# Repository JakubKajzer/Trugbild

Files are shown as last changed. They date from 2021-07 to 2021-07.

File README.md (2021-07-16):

# Trugbild
A FPGA working in serial with HDMI, for some real live video modifications. I'm making it to prove myself, that I can route highspeed PCB and to learn to code FPGA better.

## Features

- Xilinx Spartan 3 XC3S50A
- 2MB Flash memory
- 32MB DRAM memory
- Possibility to power device only from HDMI or from external input

## PCB screenshots
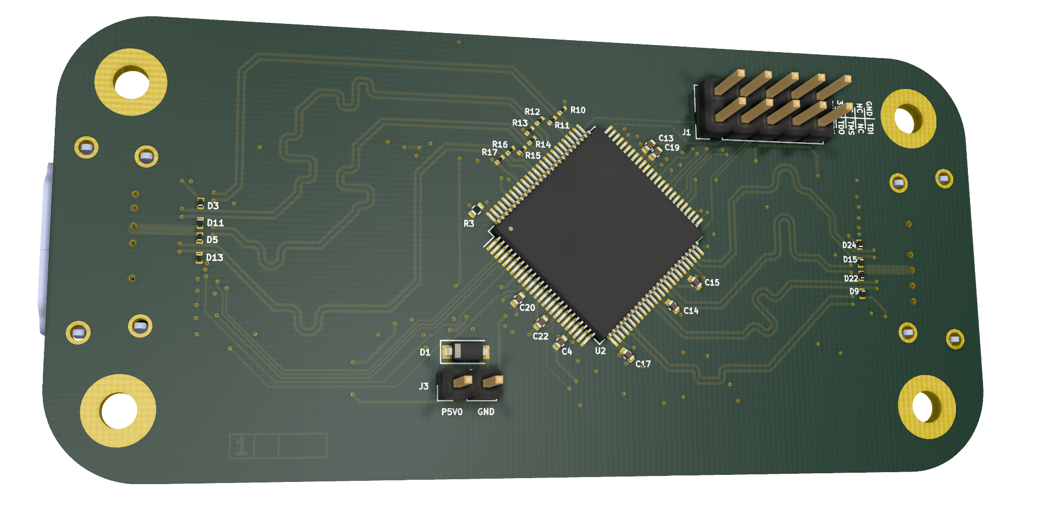
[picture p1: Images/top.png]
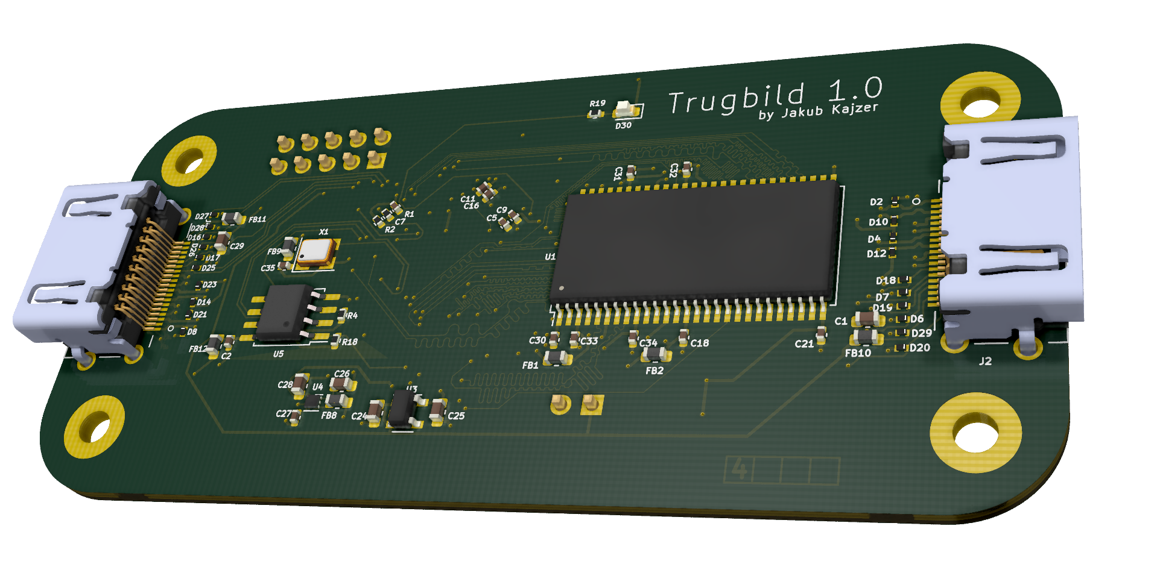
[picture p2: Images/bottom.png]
|||
|---|---|
## Why "Trugbild"
It is because Trugbild is a german word meaning _illusion_. So I think that is a good name for device which can modify what you see :)

## Develop steps
- [x] Make PCB

- [x] Order PCB fabrication
- [ ] Order elements
- [ ] Solder everything
- [ ] First run
- [ ] Try to run device only with power from HDMI (max. 50mA@5V)
- [ ] Make and test if device can transmit HDMI at Full HD
- [ ] Make some video modification while transmitting
- [ ] Try to add some kind of neuron network to face recognition
- [ ] Try to cover detected faces with some picture or someone face :)
## Comments
### Make PCB
This point took me many hours of designing because this is my first design with FPGA, so I had pretty much to learn. I'm still not sure if everything was routed least good, but I will find it out soon.
### Order PCB fabrication
For this, I used JLCPCB. They have 3.5mils clearance and track width, 0.2mm holes minimum, and four layers just for 8$. That's incredible!
But after uploading gerber files, it comes that they don't have 3.5mils clearance, but 0.09mm (3.543mils), so I must re-route some nets on PCB :( The 5 PCBs cost me total of $15.89 with delivery included.

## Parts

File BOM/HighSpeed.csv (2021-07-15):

Id | Designator | Package | Quantity | Designation | Supplier and ref
1 | REF**,REF**,REF**,REF** | MountingHole_3mm_Pad | 4 | MountingHole_3mm_Pad
2 | U1 | TSOP-II-54_22.2x10.16mm_P0.8mm | 1 | AS4C32M8SA-6TIN
3 | U2 | VQFP-100_14x14mm_P0.5mm | 1 | XC3S50A-4VQG100C
4 | J1 | PinHeader_2x05_P2.54mm_Vertical | 1 | Conn_02x05_Odd_Even
5 | U5 | SOP-8_5.28x5.23mm_P1.27mm | 1 | MX25L1636EM2I-08G
6 | R19 | R_0402_1005Metric | 1 | 1k
7 | D30 | LED_0603_1608Metric | 1 | LED
8 | R18,R4 | R_0402_1005Metric | 2 | 10k
9 | FB12,FB11,FB10,FB9,FB8,FB2,FB1 | L_0603_1608Metric | 7 | Ferrite_Bead_Small
10 | C2,C35,C34,C33,C32,C31,C30,C27,C22,C21,C20,C19,C18,C17,C16,C15,C14,C13,C11,C9,C7,C5,C4 | C_0402_1005Metric | 23 | 100nF
11 | R17,R16,R15,R14,R13,R12,R11,R10 | R_0201_0603Metric | 8 | 49R9
12 | X1 | Oscillator_SMD_SeikoEpson_SG8002CE-4Pin_3.2x2.5mm | 1 | EC5645ETTS-50.000M
13 | C1,C29,C28,C26,C25,C24 | C_0603_1608Metric | 6 | 100uF
14 | R3,R2,R1 | R_0402_1005Metric | 3 | DNP
15 | D28,D29,D27,D26,D25,D24,D23,D22,D21,D20,D19,D18,D17,D16,D15,D14,D13,D12,D11,D10,D9,D8,D7,D6,D5,D4,D3,D2 | DFN-2 | 28 | AOZ8831DI-05
16 | J4,J2 | AMPHENOL_10029449-001RLF | 2 | HDMI_A
17 | D1 | D_SOD-123 | 1 | BAT46
18 | U4 | DFN-6_1.3x1.2mm_P0.4mm | 1 | LDK130PU12R_DFN6
19 | U3 | SOT-23-5 | 1 | MIC5365-3.3YD5
20 | J3 | PinHeader_1x02_P2.54mm_Vertical | 1 | Conn_01x02

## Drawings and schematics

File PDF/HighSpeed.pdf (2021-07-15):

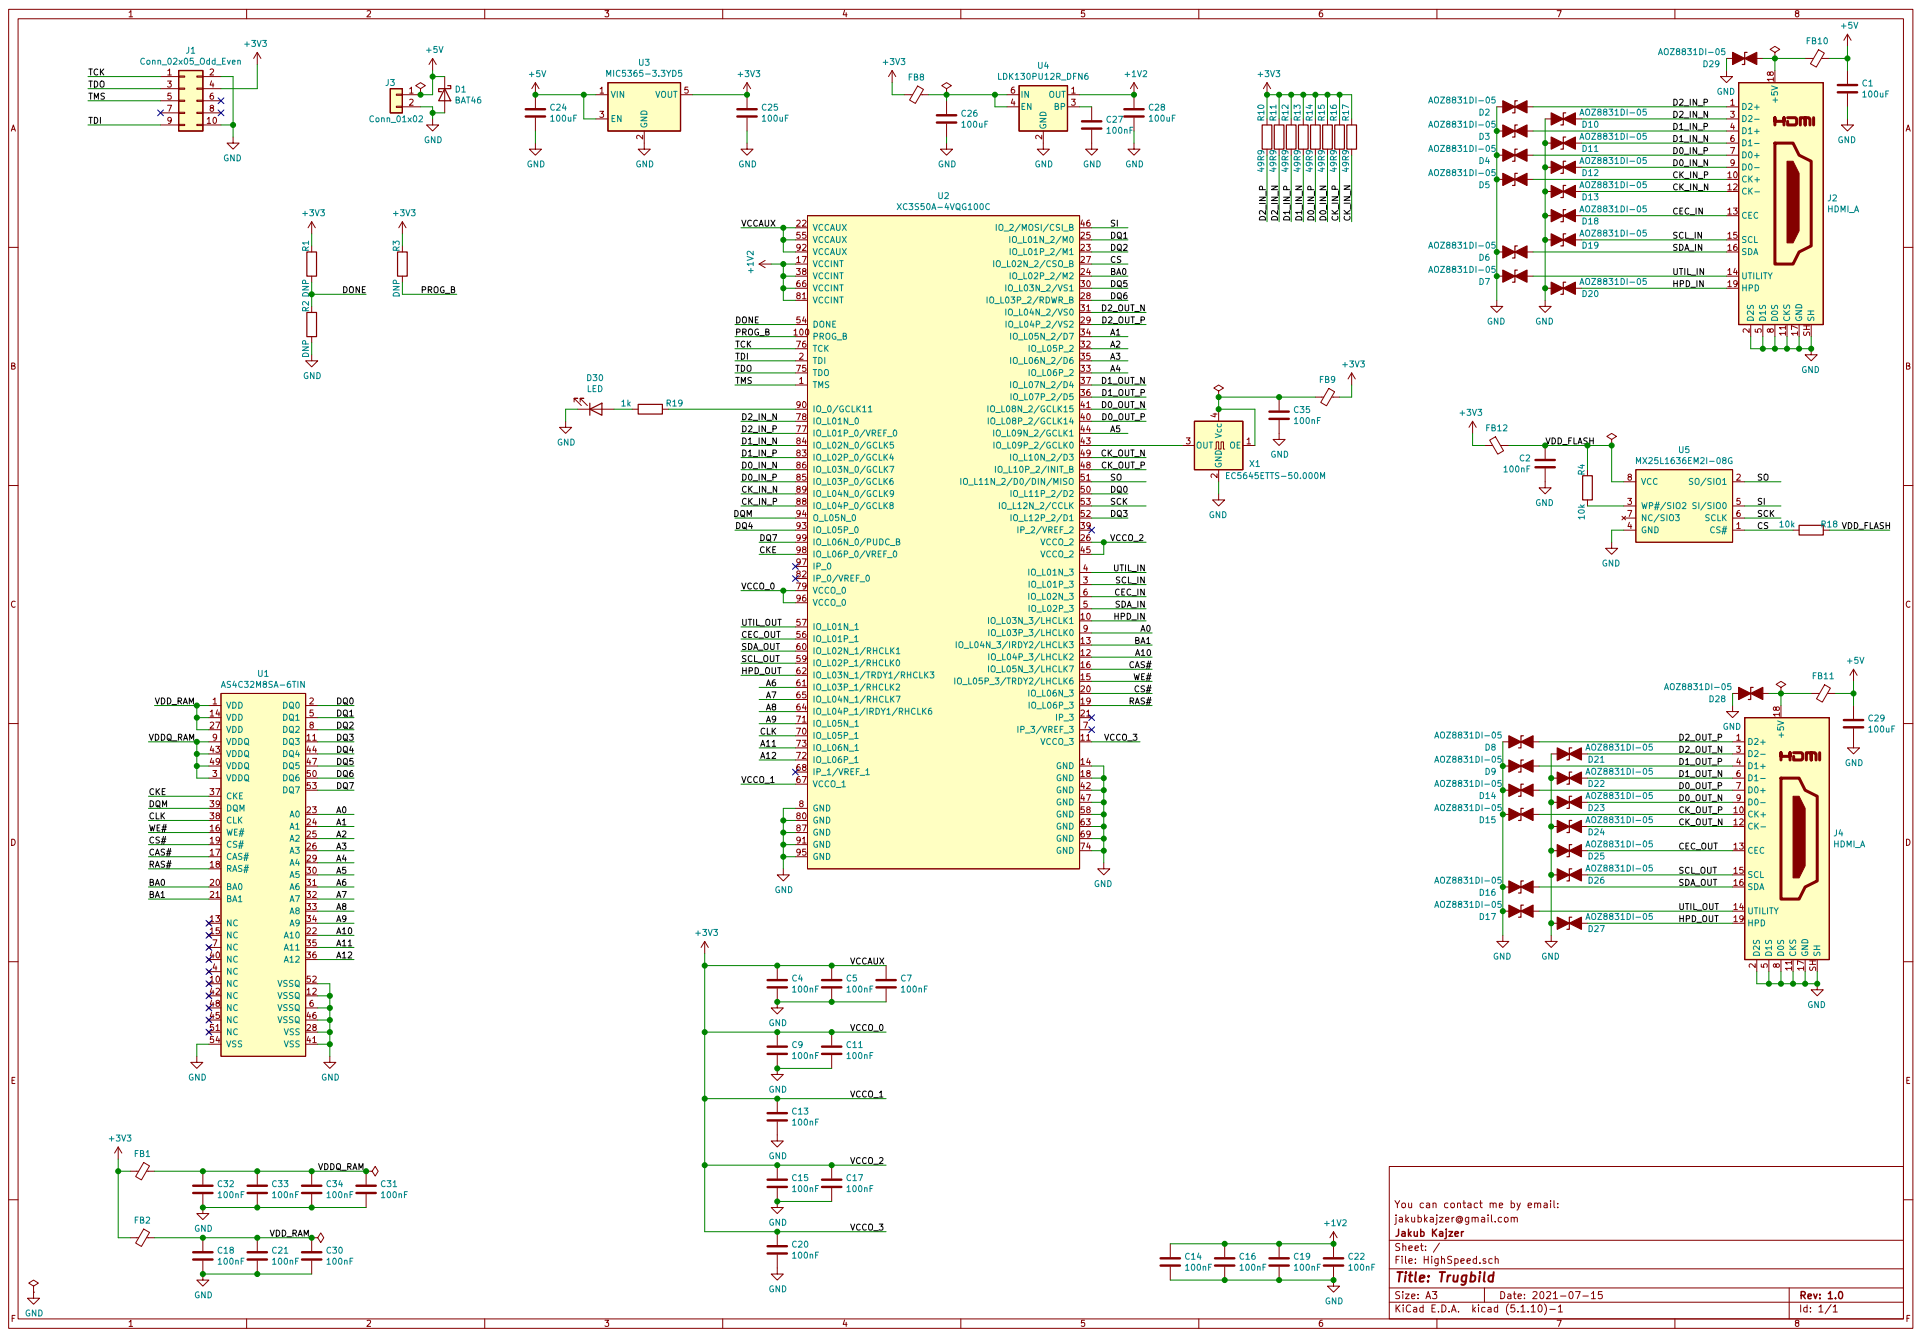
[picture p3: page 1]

You can contact me by email: C21

jakubkajzer@gmail.com
File: HighSpeed.sch Sheet: / Jakub Kajzer

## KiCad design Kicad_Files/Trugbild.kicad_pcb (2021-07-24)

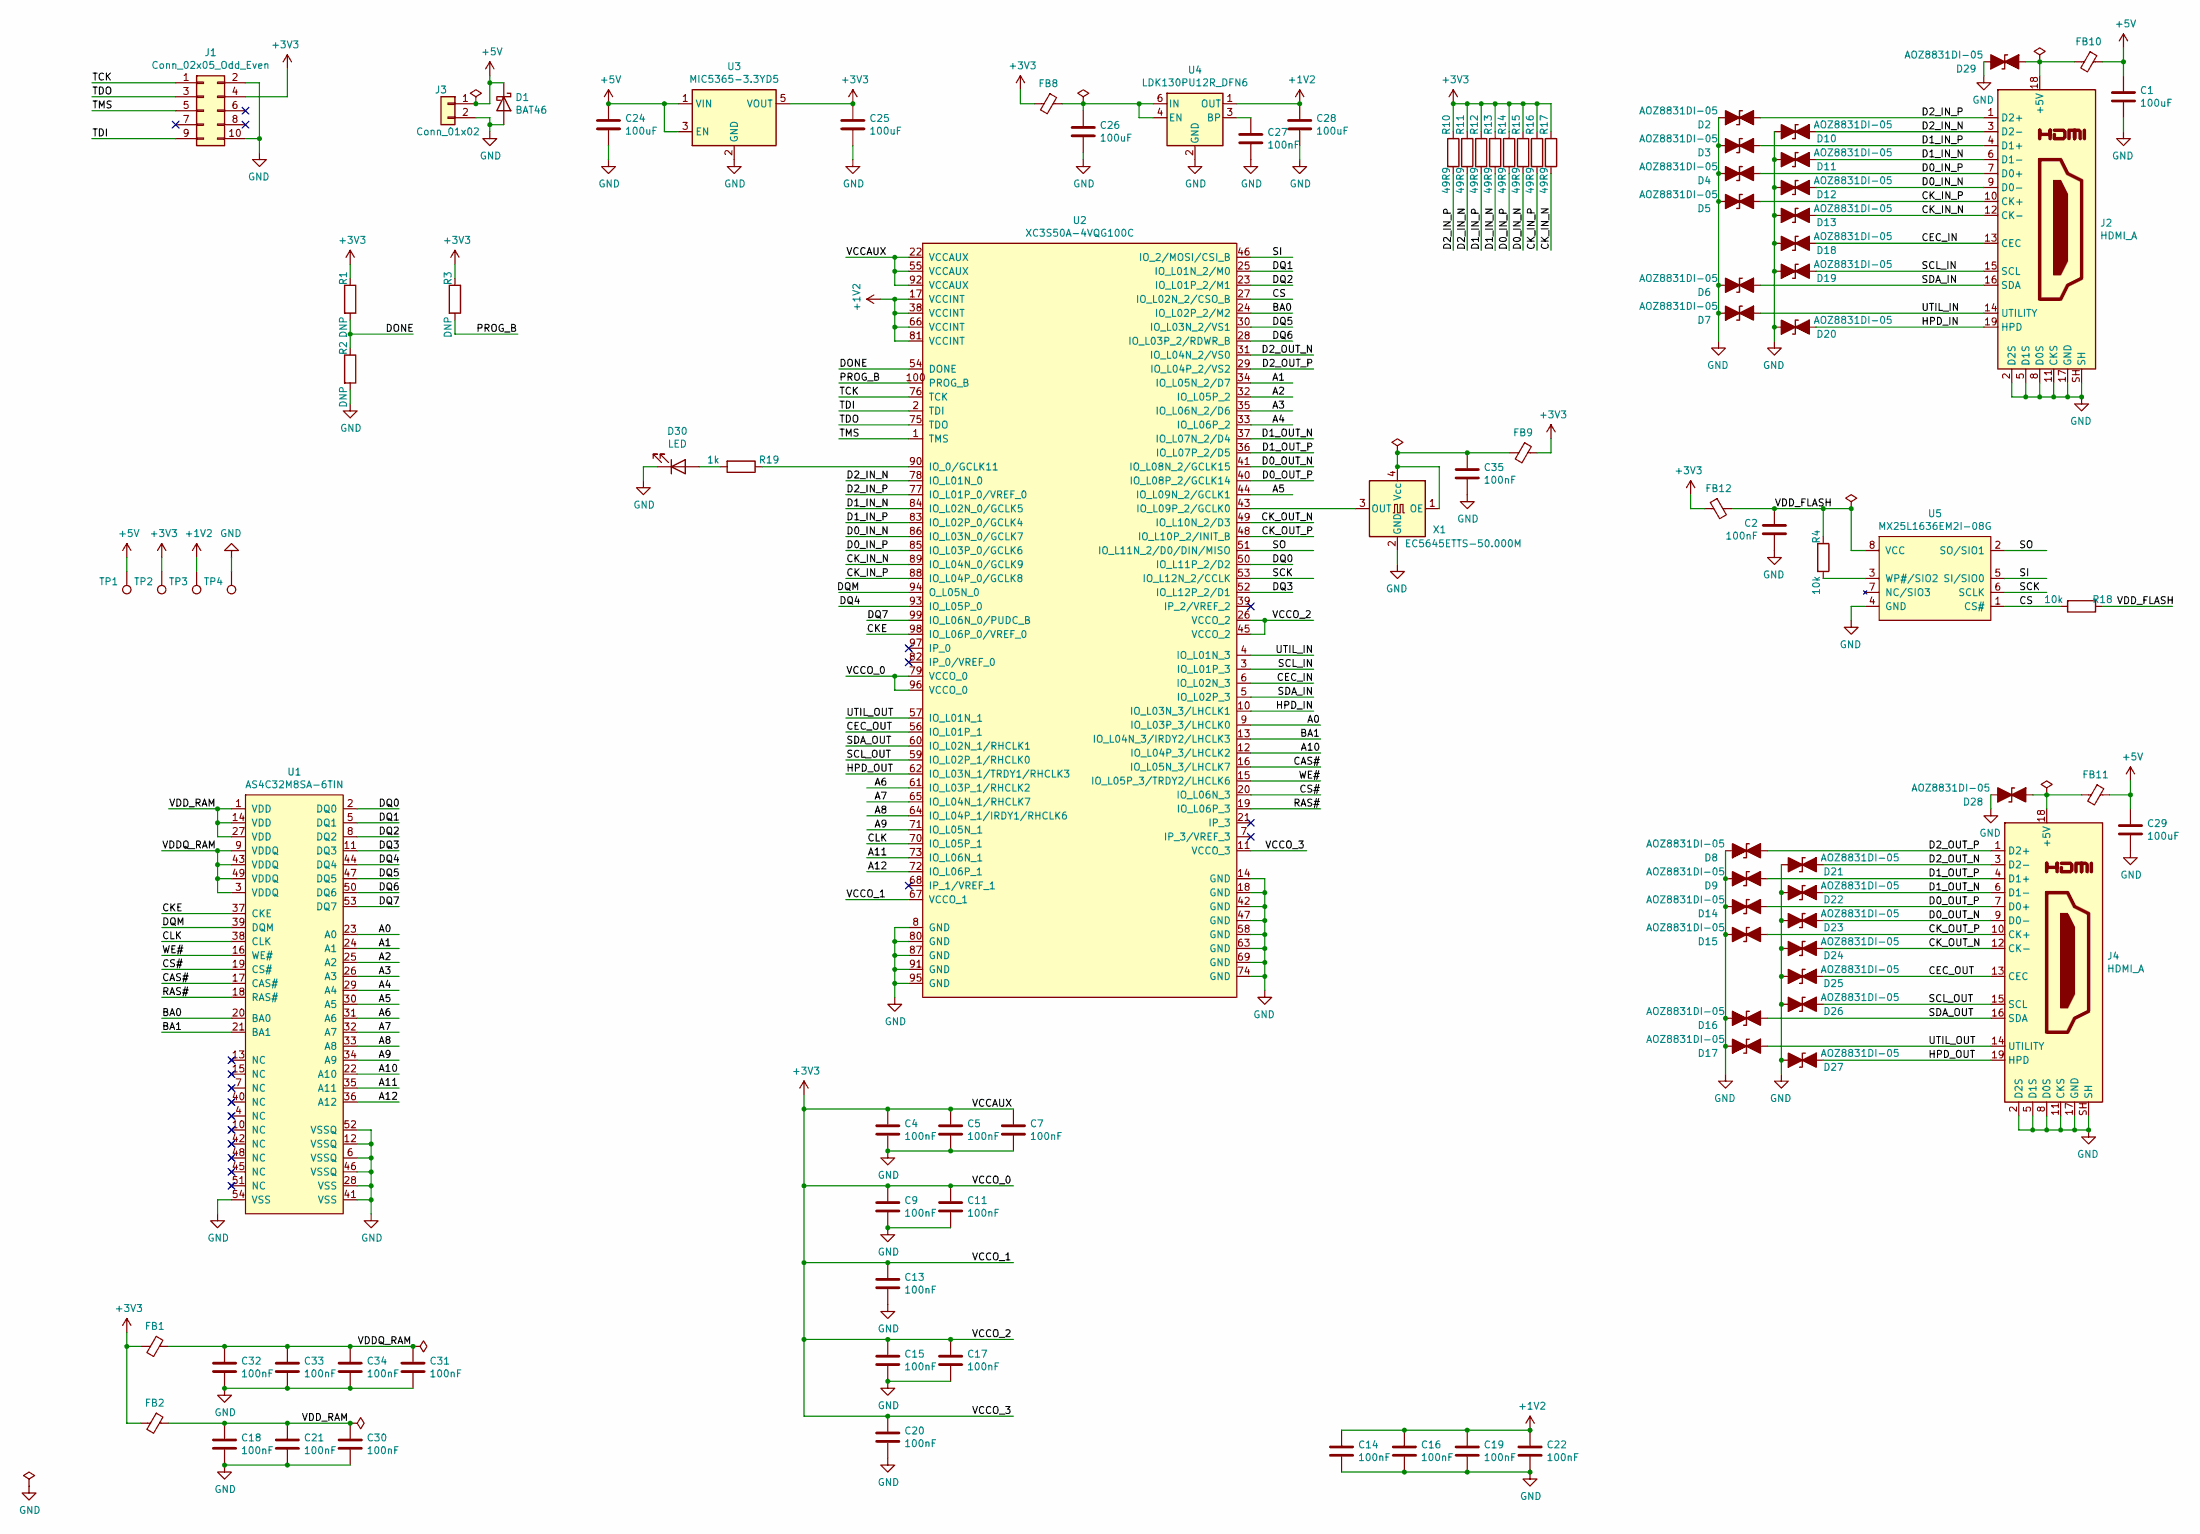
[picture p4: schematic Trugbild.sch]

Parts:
C1, C24, C25, C26, C28, C29: 100uF; C_0603_1608Metric
C2, C4, C5, C7, C9, C11, C13, C14, C15, C16, C17, C18, C19, C20, C21, C22, C27, C30, C31, C32, C33, C34, C35: 100nF; C_0402_1005Metric
D1: BAT46; D_SOD-123
D2, D3, D4, D5, D6, D7, D8, D9, D10, D11, D12, D13, D14, D15, D16, D17, D18, D19, D20, D21, D22, D23, D24, D25, D26, D27, D28, D29: AOZ8831DI-05; DFN-2
D30: LED; LED_0603_1608Metric
FB1, FB2, FB8, FB9, FB10, FB11, FB12: Ferrite_Bead_Small; L_0603_1608Metric
J1: Conn_02x05_Odd_Even; PinHeader_2x05_P2.54mm_Vertical
J2, J4: HDMI_A; AMPHENOL_10029449-001RLF
J3: Conn_01x02; PinHeader_1x02_P2.54mm_Vertical
R1, R2, R3: DNP; R_0402_1005Metric
R4, R18: 10k; R_0402_1005Metric
R10, R11, R12, R13, R14, R15, R16, R17: 49R9; R_0201_0603Metric
R19: 1k; R_0402_1005Metric
TP1, TP2, TP3, TP4: TestPoint; TestPoint_Pad_D1.0mm
U1: AS4C32M8SA-6TIN; TSOP-II-54_22.2x10.16mm_P0.8mm
U2: XC3S50A-4VQG100C; VQFP-100_14x14mm_P0.5mm
U3: MIC5365-3.3YD5; SOT-23-5
U4: LDK130PU12R_DFN6; DFN-6_1.3x1.2mm_P0.4mm
U5: MX25L1636EM2I-08G; SOP-8_5.28x5.23mm_P1.27mm
X1: EC5645ETTS-50.000M; Oscillator_SMD_SeikoEpson_SG8002CE-4Pin_3.2x2.5mm

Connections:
+1V2: C14.1, C16.1, C19.1, C22.1, C28.1, TP3.1, U2.17 (VCCINT), U2.38 (VCCINT), U2.66 (VCCINT), U2.81 (VCCINT), U4.1 (OUT); also elsewhere on the board
+3V3: C4.1, C5.1, C7.1, C9.1, C11.1, C13.1, C15.1, C17.1, C20.1, C25.1, FB1.2, FB2.2, FB8.2, FB9.1, FB12.1, J1.4, R1.1, R3.1, R10.1, R11.1, R12.1, R13.1, R14.1, R15.1, R16.1, R17.1, TP2.1, U2.11 (VCCO_3), U2.22 (VCCAUX), U2.26 (VCCO_2), U2.45 (VCCO_2), U2.55 (VCCAUX), U2.67 (VCCO_1), U2.79 (VCCO_0), U2.92 (VCCAUX), U2.96 (VCCO_0), U3.5 (VOUT); also elsewhere on the board
+5V: C1.1, C24.1, C29.1, D1.1 (K), FB10.1, FB11.1, J3.1, TP1.1, U3.1 (VIN), U3.3 (EN); also elsewhere on the board
/A0: U1.23 (A0), U2.9 (IO_L03P_3/LHCLK0)
/A1: U1.24 (A1), U2.34 (IO_L05N_2/D7)
/A2: U1.25 (A2), U2.32 (IO_L05P_2)
/A3: U1.26 (A3), U2.35 (IO_L06N_2/D6)
/A4: U1.29 (A4), U2.33 (IO_L06P_2)
/A5: U1.30 (A5), U2.44 (IO_L09N_2/GCLK1)
/A6: U1.31 (A6), U2.61 (IO_L03P_1/RHCLK2)
/A7: U1.32 (A7), U2.65 (IO_L04N_1/RHCLK7)
/A8: U1.33 (A8), U2.64 (IO_L04P_1/IRDY1/RHCLK6)
/A9: U1.34 (A9), U2.71 (IO_L05N_1)
/A10: U1.22 (A10), U2.12 (IO_L04P_3/LHCLK2)
/A11: U1.35 (A11), U2.73 (IO_L06N_1)
/A12: U1.36 (A12), U2.72 (IO_L06P_1)
/BA0: U1.20 (BA0), U2.24 (IO_L02P_2/M2)
/BA1: U1.21 (BA1), U2.13 (IO_L04N_3/IRDY2/LHCLK3)
/CAS#: U1.17 (CAS#), U2.16 (IO_L05N_3/LHCLK7)
/CEC_IN: D18.1 (A1), J2.13 (CEC), U2.6 (IO_L02N_3)
/CEC_OUT: D25.1 (A1), J4.13 (CEC), U2.56 (IO_L01P_1)
/CKE: U1.37 (CKE), U2.98 (IO_L06P_0/VREF_0)
/CK_IN_N: D13.1 (A1), J2.12 (CK-), R17.2, U2.89 (IO_L04N_0/GCLK9)
/CK_IN_P: D5.1 (A1), J2.10 (CK+), R16.2, U2.88 (IO_L04P_0/GCLK8)
/CK_OUT_N: D24.1 (A1), J4.12 (CK-), U2.49 (IO_L10N_2/D3)
/CK_OUT_P: D15.1 (A1), J4.10 (CK+), U2.48 (IO_L10P_2/INIT_B)
/CLK: U1.38 (CLK), U2.70 (IO_L05P_1)
/CS: R18.2, U2.27 (IO_L02N_2/CSO_B), U5.1 (CS#)
/CS#: U1.19 (CS#), U2.20 (IO_L06N_3)
/D0_IN_N: D12.1 (A1), J2.9 (D0-), R15.2, U2.86 (IO_L03N_0/GCLK7)
/D0_IN_P: D4.1 (A1), J2.7 (D0+), R14.2, U2.85 (IO_L03P_0/GCLK6)
/D0_OUT_N: D23.1 (A1), J4.9 (D0-), U2.41 (IO_L08N_2/GCLK15)
/D0_OUT_P: D14.1 (A1), J4.7 (D0+), U2.40 (IO_L08P_2/GCLK14)
/D1_IN_N: D11.1 (A1), J2.6 (D1-), R13.2, U2.84 (IO_L02N_0/GCLK5)
/D1_IN_P: D3.1 (A1), J2.4 (D1+), R12.2, U2.83 (IO_L02P_0/GCLK4)
/D1_OUT_N: D22.1 (A1), J4.6 (D1-), U2.37 (IO_L07N_2/D4)
/D1_OUT_P: D9.1 (A1), J4.4 (D1+), U2.36 (IO_L07P_2/D5)
/D2_IN_N: D10.1 (A1), J2.3 (D2-), R11.2, U2.78 (IO_L01N_0)
/D2_IN_P: D2.1 (A1), J2.1 (D2+), R10.2, U2.77 (IO_L01P_0/VREF_0)
/D2_OUT_N: D21.1 (A1), J4.3 (D2-), U2.31 (IO_L04N_2/VS0)
/D2_OUT_P: D8.1 (A1), J4.1 (D2+), U2.29 (IO_L04P_2/VS2)
/DONE: R1.2, R2.1, U2.54 (DONE)
/DQ0: U1.2 (DQ0), U2.50 (IO_L11P_2/D2)
/DQ1: U1.5 (DQ1), U2.25 (IO_L01N_2/M0)
/DQ2: U1.8 (DQ2), U2.23 (IO_L01P_2/M1)
/DQ3: U1.11 (DQ3), U2.52 (IO_L12P_2/D1)
/DQ4: U1.44 (DQ4), U2.93 (IO_L05P_0)
/DQ5: U1.47 (DQ5), U2.30 (IO_L03N_2/VS1)
/DQ6: U1.50 (DQ6), U2.28 (IO_L03P_2/RDWR_B)
/DQ7: U1.53 (DQ7), U2.99 (IO_L06N_0/PUDC_B)
/DQM: U1.39 (DQM), U2.94 (O_L05N_0)
/HPD_IN: D20.1 (A1), J2.19 (HPD), U2.10 (IO_L03N_3/LHCLK1)
/HPD_OUT: D27.1 (A1), J4.19 (HPD), U2.62 (IO_L03N_1/TRDY1/RHCLK3)
/PROG_B: R3.2, U2.100 (PROG_B)
/RAS#: U1.18 (RAS#), U2.19 (IO_L06P_3)
/SCK: U2.53 (IO_L12N_2/CCLK), U5.6 (SCLK)
/SCL_IN: D19.1 (A1), J2.15 (SCL), U2.3 (IO_L01P_3)
/SCL_OUT: D26.1 (A1), J4.15 (SCL), U2.59 (IO_L02P_1/RHCLK0)
/SDA_IN: D6.1 (A1), J2.16 (SDA), U2.5 (IO_L02P_3)
/SDA_OUT: D16.1 (A1), J4.16 (SDA), U2.60 (IO_L02N_1/RHCLK1)
/SI: U2.46 (IO_2/MOSI/CSI_B), U5.5 (SI/SIO0)
/SO: U2.51 (IO_L11N_2/D0/DIN/MISO), U5.2 (SO/SIO1)
/TCK: J1.1, U2.76 (TCK)
/TDI: J1.9, U2.2 (TDI)
/TDO: J1.3, U2.75 (TDO)
/TMS: J1.5, U2.1 (TMS)
/UTIL_IN: D7.1 (A1), J2.14 (UTILITY), U2.4 (IO_L01N_3)
/UTIL_OUT: D17.1 (A1), J4.14 (UTILITY), U2.57 (IO_L01N_1)
/VDDQ_RAM: C31.1, C32.1, C33.1, C34.1, FB1.1, U1.3 (VDDQ), U1.9 (VDDQ), U1.43 (VDDQ), U1.49 (VDDQ)
/VDD_FLASH: C2.1, FB12.2, R4.1, R18.1, U5.8 (VCC)
/VDD_RAM: C18.1, C21.1, C30.1, FB2.1, U1.1 (VDD), U1.14 (VDD), U1.27 (VDD)
/WE#: U1.16 (WE#), U2.15 (IO_L05P_3/TRDY2/LHCLK6)
GND: C1.2, C2.2, C4.2, C5.2, C7.2, C9.2, C11.2, C13.2, C14.2, C15.2, C16.2, C17.2, C18.2, C19.2, C20.2, C21.2, C22.2, C24.2, C25.2, C26.2, C27.2, C28.2, C29.2, C30.2, C31.2, C32.2, C33.2, C34.2, C35.2, D1.2 (A), D2.2 (A2), D3.2 (A2), D4.2 (A2), D5.2 (A2), D6.2 (A2), D7.2 (A2), D8.2 (A2), D9.2 (A2), D10.2 (A2), D11.2 (A2), D12.2 (A2), D13.2 (A2), D14.2 (A2), D15.2 (A2), D16.2 (A2), D17.2 (A2), D18.2 (A2), D19.2 (A2), D20.2 (A2), D21.2 (A2), D22.2 (A2), D23.2 (A2), D24.2 (A2), D25.2 (A2), D26.2 (A2), D27.2 (A2), D28.2 (A2), D29.2 (A2), D30.1 (K), J1.2, J1.10, J2.2 (D2S), J2.5 (D1S), J2.8 (D0S), J2.11 (CKS), J2.17 (GND), J2.SH, J3.2, J4.2 (D2S), J4.5 (D1S), J4.8 (D0S), J4.11 (CKS), J4.17 (GND), J4.SH, R2.2, TP4.1, U1.6 (VSSQ), U1.12 (VSSQ), U1.28 (VSS), U1.41 (VSS), U1.46 (VSSQ), U1.52 (VSSQ), U1.54 (VSS), U2.8 (GND), U2.14 (GND), U2.18 (GND), U2.42 (GND), U2.47 (GND), U2.58 (GND), U2.63 (GND), U2.69 (GND), U2.74 (GND), U2.80 (GND), U2.87 (GND), U2.91 (GND), U2.95 (GND), U3.2 (GND), U4.2 (GND), U5.4 (GND), X1.2 (GND); also elsewhere on the board
unnamed: C26.1, FB8.1, U4.4 (EN), U4.6 (IN)
unnamed: C27.1, U4.3 (BP)
unnamed: C35.1, FB9.2, X1.1 (OE), X1.4 (Vcc)
unnamed: D28.1 (A1), FB11.2, J4.18 (+5V)
unnamed: D29.1 (A1), FB10.2, J2.18 (+5V)
unnamed: D30.2 (A), R19.2
unnamed: R4.2, U5.3 (WP#/SIO2)
unnamed: R19.1, U2.90 (IO_0/GCLK11)
unnamed: U2.43 (IO_L09P_2/GCLK0), X1.3 (OUT)

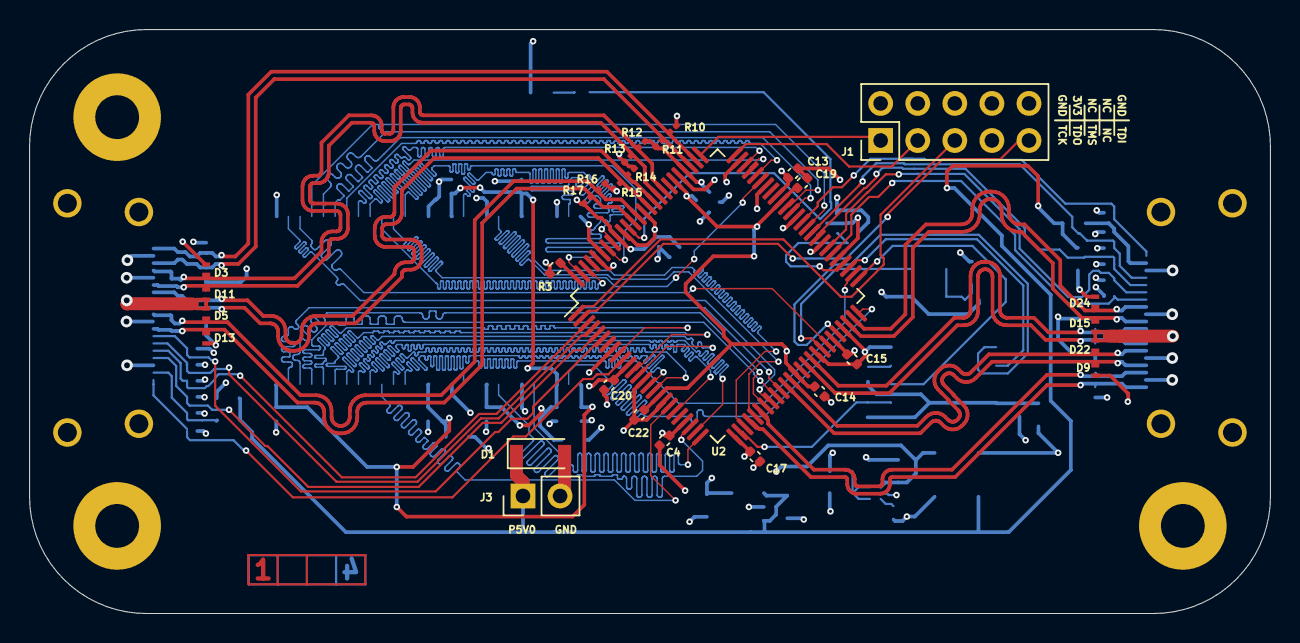
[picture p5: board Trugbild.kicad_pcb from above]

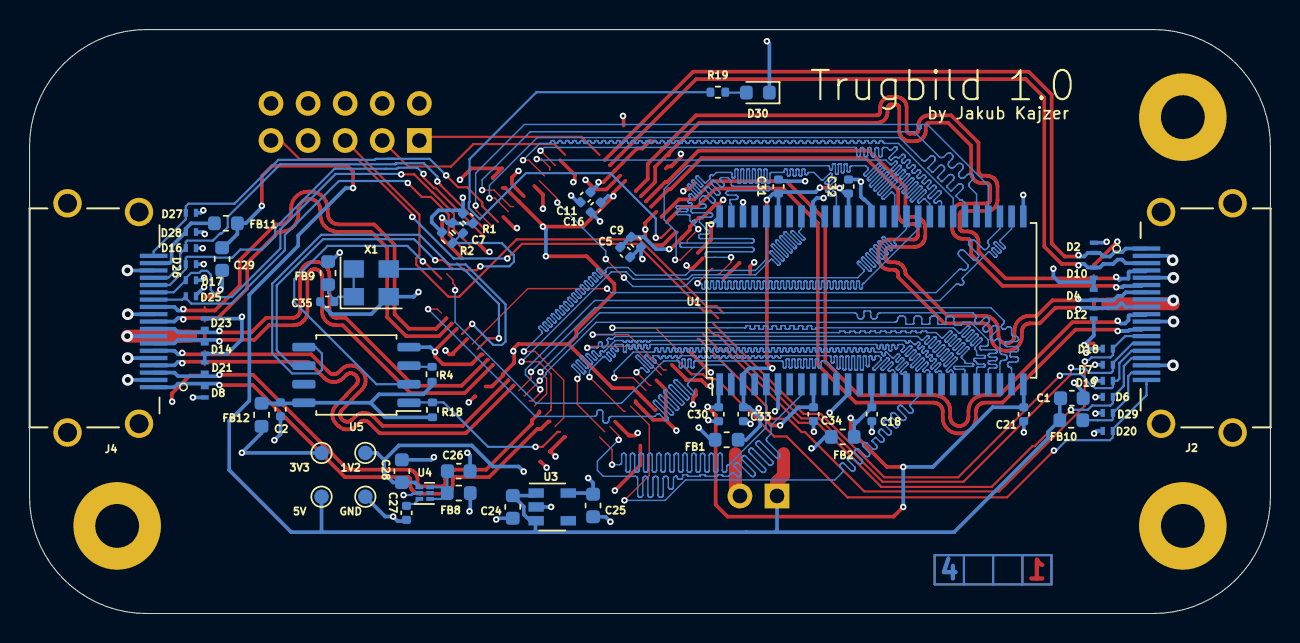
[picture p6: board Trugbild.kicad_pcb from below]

Board: 4 copper layers, 85.0 x 40.0 mm, 94 parts (65 on the bottom side), 82 nets.

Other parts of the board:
1V2, 3V3, 5V: TestPoint; TestPoint_Pad_D1.0mm
GND: TestPoint; TestPoint_Pad_D1.0mm

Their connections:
+1V2: 1V2.1; also elsewhere on the board
+3V3: 3V3.1; also elsewhere on the board
+5V: 5V.1; also elsewhere on the board
GND: GND.1; also elsewhere on the board

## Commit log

2021-07-15 Fabrication update and images
    [PCB-B_Cu.gbr, PCB-B_Mask.gbr, PCB-B_SilkS.gbr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]
2021-07-24 fix for JLCPCB clearance
    [PCB.kicad_pcb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]
2021-07-24 fix for clearance v2
    [Trugbild-B_Cu.gbr, Trugbild-B_Mask.gbr, Trugbild-B_SilkS.gbr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]
